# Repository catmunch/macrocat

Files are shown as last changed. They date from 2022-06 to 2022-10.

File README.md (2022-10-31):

# Macrocat

A cat like macro keyboard/numpad.

macrocat

## Resources
- [Designer Spreadsheet](https://docs.google.com/spreadsheets/d/15iPMkPPelqXUuJzfWze6s_fHAjqMbbhKXIEQs6-oLG8/edit#gid=0)
- [QMK Docs](https://docs.qmk.fm/#/)
- [ai03](https://wiki.ai03.com/books)
- [Keyboard Layout Editor](http://www.keyboard-layout-editor.com/#/gists/0d682a6dd41d7de2ae32d8b280f85d39)
- [ai03 Plate Generator](https://kbplate.ai03.com/)
- [Keyswitch KiCAD Library](https://github.com/perigoso/keyswitch-kicad-library) Licensed in CC-BY-SA 4.0

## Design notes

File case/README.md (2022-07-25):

# Case

This is a sandwich mount styled case.

The program used is Openscad.

The top and bottom case is 3D printed well the plate cut out of 5mm acrylic.
Execute the ``render.sh`` to export to generate STL and DXF files.

## BOM

- 8 x M3 x 14mm screws (flat head, head less than 2mm thick, 7mm wide)
- 8 x M3 Heat thread inserts, 5mm diameter, 4mm tall

## TODO

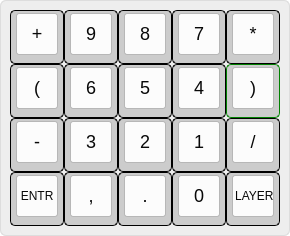
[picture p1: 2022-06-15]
layout/big.png

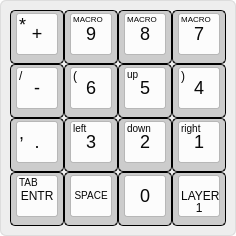
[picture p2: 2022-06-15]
layout/small.png

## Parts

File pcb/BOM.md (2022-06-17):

BOM

|Designator|Name|Quantity|Link|
|---|----|---|----|
|U1|ATmega32U4-MU|1||
|D1-D16|1N4148W SOD-123|16||
|MX1-MX16|Kailh Hotswap Socket|16||
|R1-R2|22 Ohm 0805 Resistor|2||
|R3-R4|10k Ohm 0805 Resistor|2||
|R5-R6|5.1k Ohm 0805 Resistor|2||
|C1,C4,C6|0.1uF 0805 Capacitor|3||
|C2,C3|22pF 0805 Capacitor|2||
|C5|1uF 0805 Capacitor|1||
|C7|10uF 0805 Capacitor|1||
|F1|500mA 1206 Fuse|1||
|Y1|16MHz 3225 Crystal|1||
|J1|USB-C Mid Mount Connector|1||
|RESET1|6.7*4.1mm Button|1||
|KNOB1|EC11 Rotary Encoder|1||
|OL1|4-pin 2.54mm Socket|1||

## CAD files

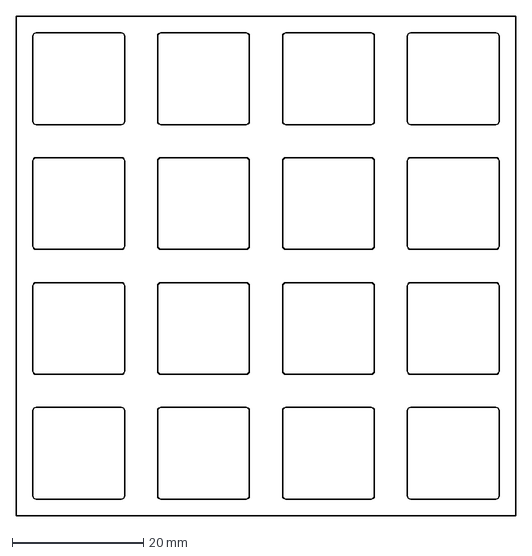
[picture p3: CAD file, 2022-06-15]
case/plate/4x4 plate.dxf
76.2 x 76.2 mm

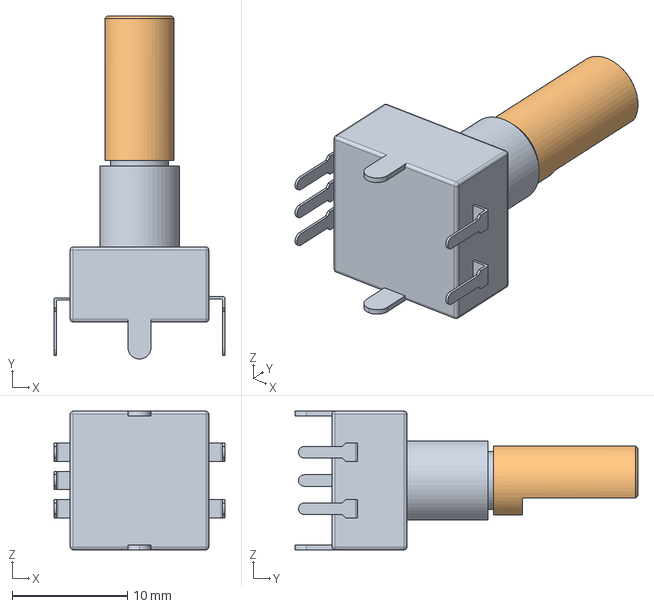
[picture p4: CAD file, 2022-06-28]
pcb/horfee-rotary-encoder/Rotary Encoder.step
14.8 x 29.7 x 12.0 mm

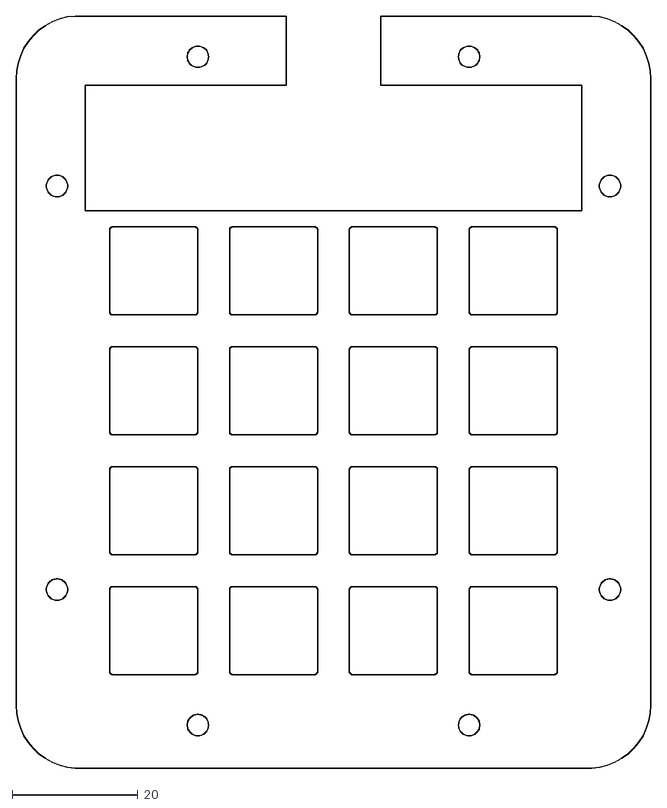
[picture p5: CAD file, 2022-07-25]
case/export/plate.dxf
100.9 x 119.5

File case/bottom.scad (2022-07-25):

bottom_thickness = 4;
fillet_width = 3;
pcb_height = 4;	// 2mm for pcb, 2mm for hotswap/pins
side_height = pcb_height+2*margins;

module bottomCurve() {
	translate([0, 0, -side_height])
	difference(){
		// Rounding
		minkowski() {
			// Offset and -fillet_width to account for extra minkowski size
			translate([0, 0, -(bottom_thickness-fillet_width)])
				linear_extrude(bottom_thickness)
				offset(-fillet_width)
				drawSideProfile();

			// Sphere to run fillet with 
			sphere(fillet_width);
		}

		// Cut away 
		linear_extrude(2*(fillet_width+bottom_thickness))
			offset(1)	// openscad cutting glitch
			drawSideProfile();
	}
}

module sideWall() {
	translate([0, 0, -side_height])
		linear_extrude(side_height)
		difference() {
			drawSideProfile();

			translate([0, extra_pcb_height/2])
				offset(pcb_offset+margins)
				square([plate_width, plate_height+extra_pcb_height], center=true);
		}
}

module bottom() {
	difference() { 
		union() {
			sideWall();
			bottomCurve();
		}

		screws();
		bottomCaseCutout();
		cat();
	}
}

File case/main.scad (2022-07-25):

// Rendering mode (preview, plate, bottom, top)
mode = "preview";	// Leave on preview for rendering

// Spacing needed for 1 keyswitch
u = 19.05;

// Extra spacing between each component
margins = 1;

// Render prettier surfaces
$fn = 50;

include <plate.scad>
include <side profile.scad>
include <top.scad>
include <bottom.scad>
include <screw.scad>
include <typec.scad>
include <weight.scad>

// Rendering
if (mode == "preview") {
	% plate();
	top();
	bottom();
} else if (mode == "plate") {
	drawPlate();
} else if (mode == "bottom") {
	bottom();
} else if (mode == "top") {
	top();
} else {
	echo("Syntax error!");
}

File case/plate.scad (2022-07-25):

// Parameters
pcb_offset = 1.333;	// 1.333mm on pcb
plate_width = 4*u;
plate_height = 4*u;
extra_pcb_height = 20;
plate_thickness = 5;

// Calculations
total_plate_height = plate_height + extra_pcb_height;
total_plate_width = plate_width;

module center_plate() {
	difference() {
		// Plate shape
		translate([0, (extra_pcb_height-pcb_offset)/2])
			square([total_plate_width+2*pcb_offset, total_plate_height+pcb_offset], center=true);

		// Cutout for plate
		difference() {
			square([plate_width, plate_height], center=true);

			import("./plate/4x4 plate.svg", center=true);
		}

		// Cutout for pcb components
		translate([0, (plate_height+extra_pcb_height)/2])	// right ontop of plate
			square([plate_width+(pcb_offset+margins)*2, extra_pcb_height], center=true);
	}
}

module drawPlate() {
	union() {
		difference() {
			drawSideProfile();
			
			translate([0, (extra_pcb_height-pcb_offset)/2])
				square([total_plate_width+2*pcb_offset, total_plate_height+pcb_offset], center=true);

			plateScrewHoles();
			plateCutout();
		}

		center_plate();
	}
}

module plate() {
	difference() {
		linear_extrude(plate_thickness)
			drawPlate();

		screws();
	}
}

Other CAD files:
case/export/bottom case.stl
case/export/top case.stl
case/sandwich.scad
case/screw.scad
case/side profile.scad
case/top.scad
case/typec.scad
case/weight.scad

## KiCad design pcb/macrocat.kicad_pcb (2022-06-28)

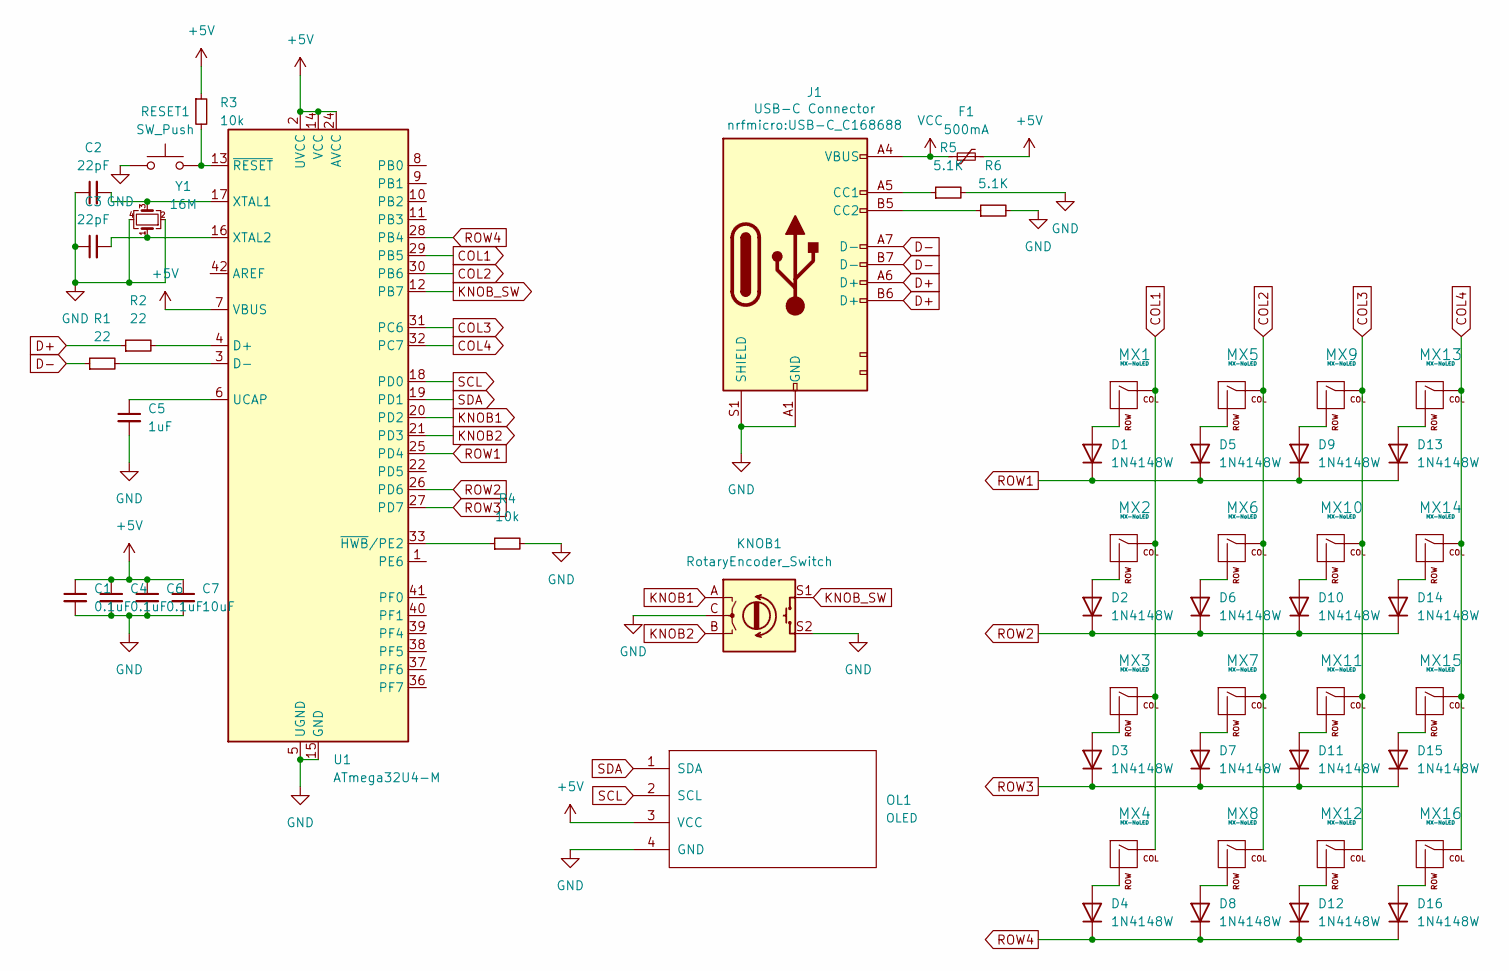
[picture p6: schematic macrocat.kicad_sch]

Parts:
C1, C4, C6: 0.1uF; C_0805_2012Metric
C2, C3: 22pF; C_0805_2012Metric
C5: 1uF; C_0805_2012Metric
C7: 10uF; C_0805_2012Metric
D1, D2, D3, D4, D5, D6, D7, D8, D9, D10, D11, D12, D13, D14, D15, D16: 1N4148W; D_SOD-123_back
F1: 500mA; Fuse_1206_3216Metric
J1: USB-C Connector; USB-C_C168688
KNOB1: RotaryEncoder_Switch; RotaryEncoder_Alps_EC11E-Switch_Vertical_H20mm
MX1, MX2, MX3, MX4, MX5, MX6, MX7, MX8, MX9, MX10, MX11, MX12, MX13, MX14, MX15, MX16: MX-NoLED; MXOnly-1U-Hotswap
OL1: OLED; OLED_v2
R1, R2: 22; R_0805_2012Metric
R3, R4: 10k; R_0805_2012Metric
R5, R6: 5.1K; R_0805_2012Metric
RESET1: SW_Push; SW_DIP_SPSTx01_Slide_6.7x4.1mm_W6.73mm_P2.54mm_LowProfile_J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
U1: ATmega32U4-M; QFN-44-1EP_7x7mm_P0.5mm_EP5.2x5.2mm
Y1: 16M; Crystal_SMD_3225-4Pin_3.2x2.5mm

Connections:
+5V: C1.1, C4.1, C6.1, C7.1, F1.2, OL1.3 (VCC), R3.1, U1.2 (UVCC), U1.7 (VBUS), U1.14 (VCC), U1.24 (AVCC), U1.34 (VCC), U1.44 (AVCC)
COL1: MX1.1 (COL), MX2.1 (COL), MX3.1 (COL), MX4.1 (COL), U1.29 (PB5)
COL2: MX5.1 (COL), MX6.1 (COL), MX7.1 (COL), MX8.1 (COL), U1.30 (PB6)
COL3: MX9.1 (COL), MX10.1 (COL), MX11.1 (COL), MX12.1 (COL), U1.31 (PC6)
COL4: MX13.1 (COL), MX14.1 (COL), MX15.1 (COL), MX16.1 (COL), U1.32 (PC7)
D+: J1.A6 (D+), J1.B6 (D+), R2.1
D-: J1.A7 (D-), J1.B7 (D-), R1.1
GND: C1.2, C2.1, C3.1, C4.2, C5.2, C6.2, C7.2, J1.A1 (GND), J1.S1 (SHIELD), KNOB1.C, KNOB1.S2, OL1.4 (GND), R4.2, R5.2, R6.2, RESET1.1, U1.5 (UGND), U1.15 (GND), U1.23 (GND), U1.35 (GND), U1.43 (GND), U1.45 (GND), Y1.2, Y1.4
KNOB1: KNOB1.A, U1.20 (PD2)
KNOB2: KNOB1.B, U1.21 (PD3)
KNOB_SW: KNOB1.S1, U1.12 (PB7)
unnamed: C2.2, U1.17 (XTAL1), Y1.3
unnamed: C3.2, U1.16 (XTAL2), Y1.1
unnamed: C5.1, U1.6 (UCAP)
unnamed: D1.2 (A), MX1.2 (ROW)
unnamed: D2.2 (A), MX2.2 (ROW)
unnamed: D3.2 (A), MX3.2 (ROW)
unnamed: D4.2 (A), MX4.2 (ROW)
unnamed: D5.2 (A), MX5.2 (ROW)
unnamed: D6.2 (A), MX6.2 (ROW)
unnamed: D7.2 (A), MX7.2 (ROW)
unnamed: D8.2 (A), MX8.2 (ROW)
unnamed: D9.2 (A), MX9.2 (ROW)
unnamed: D10.2 (A), MX10.2 (ROW)
unnamed: D11.2 (A), MX11.2 (ROW)
unnamed: D12.2 (A), MX12.2 (ROW)
unnamed: D13.2 (A), MX13.2 (ROW)
unnamed: D14.2 (A), MX14.2 (ROW)
unnamed: D15.2 (A), MX15.2 (ROW)
unnamed: D16.2 (A), MX16.2 (ROW)
unnamed: J1.A5 (CC1), R5.1
unnamed: J1.B5 (CC2), R6.1
unnamed: R1.2, U1.3 (D-)
unnamed: R2.2, U1.4 (D+)
unnamed: R3.2, RESET1.2, U1.13 (~RESET)
unnamed: R4.1, U1.33 (~HWB/PE2)
ROW1: D1.1 (K), D5.1 (K), D9.1 (K), D13.1 (K), U1.25 (PD4)
ROW2: D2.1 (K), D6.1 (K), D10.1 (K), D14.1 (K), U1.26 (PD6)
ROW3: D3.1 (K), D7.1 (K), D11.1 (K), D15.1 (K), U1.27 (PD7)
ROW4: D4.1 (K), D8.1 (K), D12.1 (K), D16.1 (K), U1.28 (PB4)
SCL: OL1.2 (SCL), U1.18 (PD0)
SDA: OL1.1 (SDA), U1.19 (PD1)
VCC: F1.1, J1.A4 (VBUS)

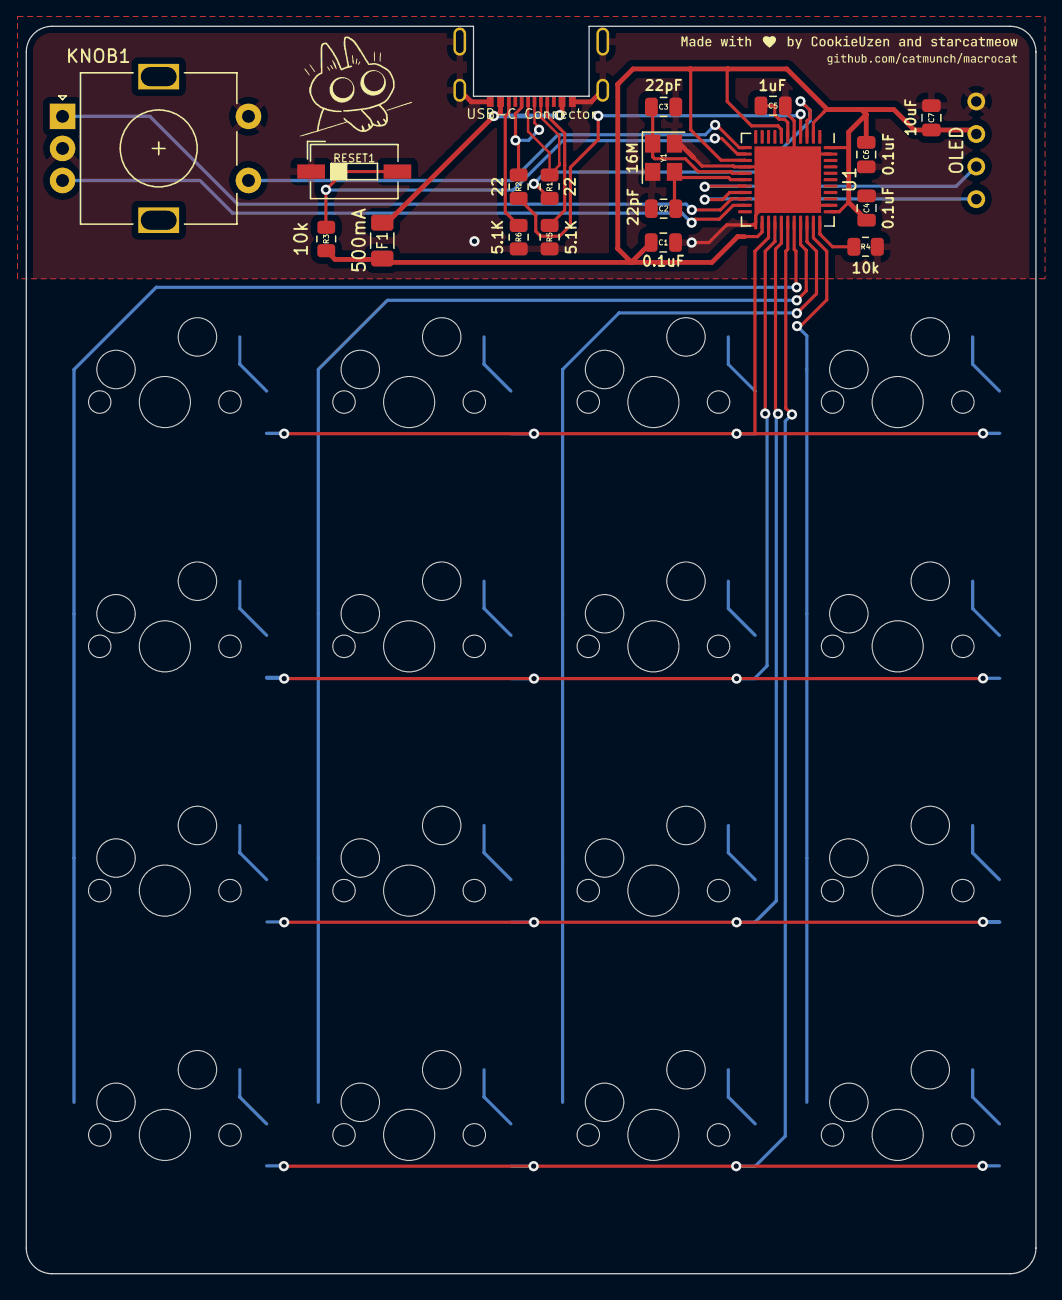
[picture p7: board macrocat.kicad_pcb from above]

Board: 2 copper layers, 78.7 x 97.3 mm, 52 parts (0 on the bottom side), 43 nets.

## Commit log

2022-06-14 add footprint libs
    [macrocat.kicad_pcb, macrocat.kicad_sch]
2022-06-14 initial layout + plate
    [4x4 plate.dxf]
2022-06-15 finish schematic diagram
    [macrocat.kicad_sch]
2022-06-15 finish pcb layout
    [macrocat.kicad_pcb, macrocat.kicad_sch]
2022-06-15 routed by freerouter
    [macrocat.dsn, macrocat.kicad_pcb]
2022-06-15 fix some bug in pcb
    [macrocat.kicad_pcb]
2022-06-15 refill the ground
2022-06-15 adjust some figures on pcb
    [macrocat.kicad_pcb, macrocat.kicad_sch]
2022-06-15 plate design 1.0
    [bottom_case.stl, plate.dxf, sandwich.scad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]
2022-06-15 optimize mcu part wiring
    [macrocat.dsn, macrocat.kicad_pcb, macrocat.kicad_sch]
2022-06-15 plate design 1.1
    [bottom_case.stl, plate.dxf, sandwich.scad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]
2022-06-17 add some cat
    [macrocat.kicad_pcb]
2022-06-17 plate design 1.2
    [sandwich.scad]
2022-06-17 plate design 1.2.1
    Fixed some major bugs, added screw holes on bottom case, moved to M2.5
    screws
    [sandwich.scad]
2022-06-17 change mcu to atmega32u4-mu
    [macrocat.kicad_pcb, macrocat.kicad_sch]
2022-06-17 add plate screw holes :)
    [sandwich.scad]
2022-06-18 plate design 1.2.2
    Changed some variable names
    [sandwich.scad]
2022-06-18 case design 1.2.3
    Add top housing screws
    [sandwich.scad]
2022-06-18 case design 1.2.4
    Added type c port
    [sandwich.scad]
2022-06-18 Case design 1.2.5
    increase type c hole
    [sandwich.scad]
2022-06-18 reduce side clearance
    [sandwich.scad]
2022-06-18 increase side clearance
    [sandwich.scad]
2022-06-20 plate design 1.2.6
    [bottom case.stl, plate.dxf, sandwich.scad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]
2022-06-20 seperated openscad files
    [bottom case.stl, bottom.scad, main.scad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]
2022-06-28 create 3d model
    [Rotary Encoder.step, macrocat.kicad_pcb, macrocat.kicad_sch]
2022-06-28 migrate the stl to git lfs
2022-06-28 plate v0.1
    Made the plate without the surronding casing for support.
    [4x4 plate.dxf, bottom.scad, main.scad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]
2022-06-29 plate update + top case
    [main.scad, plate.scad, side profile.scad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]
2022-06-30 Minor fixes to margins and keycap spacing
    [plate.scad, side profile.scad, top.scad]
2022-07-01 Bottom case design
    [bottom.scad, main.scad]
2022-07-24 added screw holes, tweaked variables
    [bottom.scad, main.scad, plate.scad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]
2022-07-25 added type c hole and fixed plate screw holes
    [bottom.scad, main.scad, plate.scad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]
2022-07-25 add weight
    [bottom.scad, main.scad, weight.scad]
2022-07-25 Added render script, fixed type c cutout on plate
    [main.scad, plate.dxf, top case.stl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]
2022-07-25 lfs + deepen engraving
    [top case.stl, weight.scad]
2022-07-25 rev 2.0.0
    [bottom case.stl, bottom.scad, screw.scad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]
